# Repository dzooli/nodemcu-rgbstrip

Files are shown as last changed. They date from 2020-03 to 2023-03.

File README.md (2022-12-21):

# nodemcu-rgbstrip

FOSSA Status (https://app.fossa.io/projects/git%2Bgithub.com%2Fdzooli%2Fnodemcu-rgbstrip?ref=badge_shield)


This project is a quick study for home automation with Domoticz, NodeMCU WiFi and an RGB LED strip.

## Control an RGB Led strip with NodeMCU using Domoticz RGB Dimmer controller

### HW Components

- Raspberry Pi3
- NodeMCU
- Transistors
- Voltage regulators
- Resistances
- RGB LED strip

### SW Components

- IDE: PlatformIO
- ESP8266 Board family for Arduino
- WiFi AP (currently a Raspberry Pi3)
- WifiManager library for Arduino
- Domoticz on the RPi3

[Details here](https://github.com/dzooli/nodemcu-rgbstrip/blob/master/doc/devlog.md)

## License

FOSSA Status (https://app.fossa.io/projects/git%2Bgithub.com%2Fdzooli%2Fnodemcu-rgbstrip?ref=badge_large)

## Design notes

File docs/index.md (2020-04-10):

# Development of a Domoticz controlled ESP8266 RGB LED Strip Dimmer

## Introduction

Main purpose of this project is to create a WiFi controlled RGB lamp and integrate it into the Domoticz ecosystem. This is a learning oriented project for myself not a production-ready one.

Secondary goal is to use free and/or Open Source Software whenever is possible.

## System overview

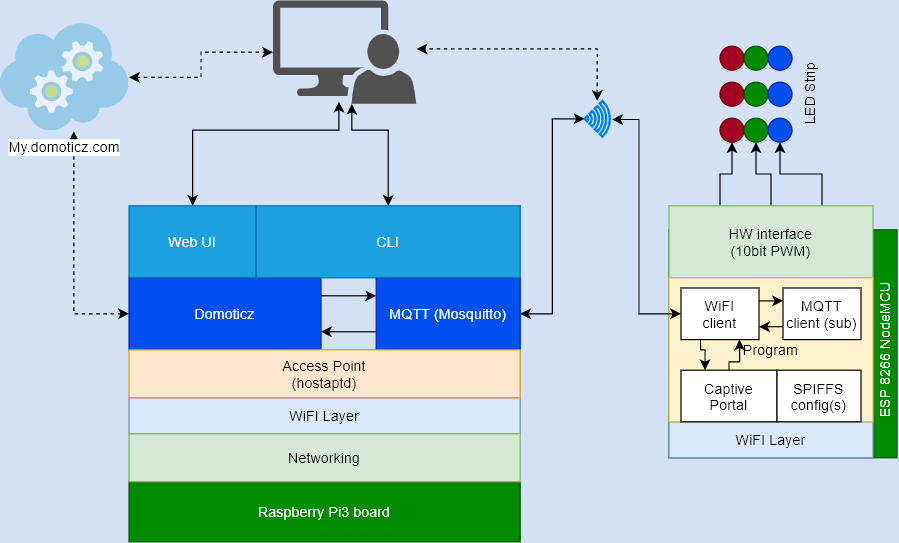
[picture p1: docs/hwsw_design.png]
Overall system design


## Client circuit

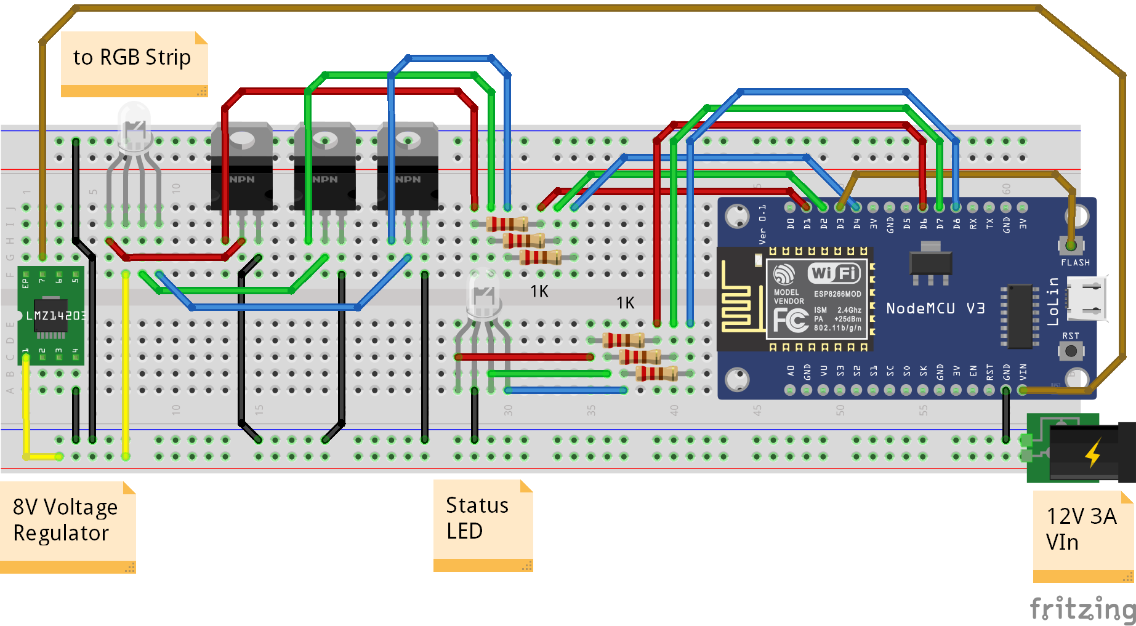
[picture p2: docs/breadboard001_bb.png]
Client schematic


## Captive portal
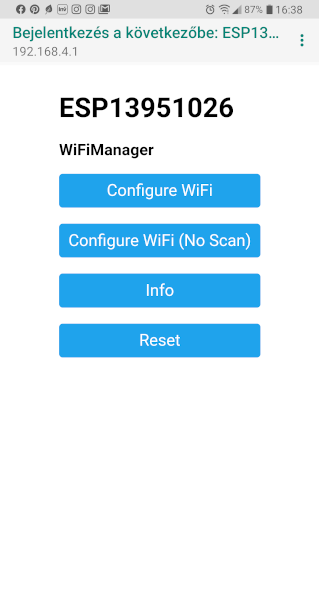
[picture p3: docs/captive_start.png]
Captive portal main

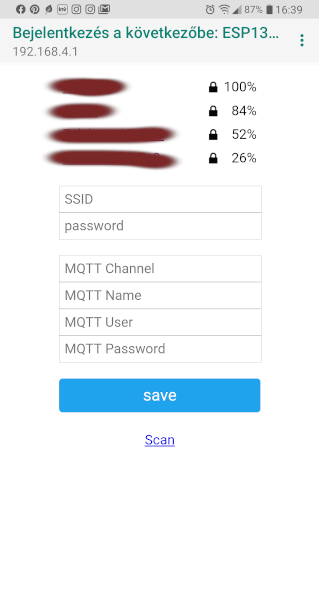
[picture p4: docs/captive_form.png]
Captive portal form


### Why Domoticz

- Good documentation with lot of examples
- Tons of ready-made sensors and actuators
- Active development (yearly stable major versions)
- Easy setup (unpack, setup and run as a service)
- **MQTT capable** => custom sensors with small effort (see the running External Pi Temperature script below)

#### Example custom script (cputemp2domoticz)

Send the DS3121's temparature sensor's value to Domoticz in every REFRESH=5 secs using basic Unix commands. The sensor index in Domoticz is _1_ in this example.

```bash
#!/bin/bash

export MQTTHOST=localhost; 
export TEMP_IDX=1; 
export REFRESH=5

while true; do
  echo '{"idx": '${TEMP_IDX}',"nvalue": 0.00, "svalue":"'$(sensors -u| grep temp1_input| \
  cut -d\  -f4)'"}' | mosquitto_pub -h $MQTTHOST -u xxxx -P yyyyy -t 'domoticz/in' -l  
  sleep ${REFRESH}
done
```

#### Run it as a "soft-daemon"

```bash
#!/bin/bash
export SCREENNAME="scriptedDomoticz"

for scriptname in *2domoticz; do 
    echo "Starting ${scriptname} in a detached screen..."
    screen -dmS ${SCREENNAME} ./${scriptname}
done    
```

## Used Tools and external libraries

- Json Assistant: https://arduinojson.org/v5/assistant
- Mosquitto MQTT server and CLI tools
- Flooplanner: https://floorplanner.com
- Arduino IDE v1.8.10 with 3rd-party ESP8266 devtools
- Marp - Markdown based presentation generator with built-in server and file watcher
- Drawing.io for diagram creation
- [Fritzing](https://fritzing.org) for BreadBoard sketching
- Eagle for schematic and PCB design (_coming soon_)

## Problems and solutions

- Chrome has JS cache -> IP has been changed but there was no HTTP error message just a Domoticz-like page with "Offline" message comes from the cache -> solution: check the IP address after a router reboot :)
- FPSTR is not working properly with ESP8266 2.4.1-> use F("") (inline PROGMEM strings ) instead
- Domoticz's Dimmer MQTT packet is bigger than 400 bytes, PubSubClient has a 128 bytes buffer -> Increase buffer size to 512 bytes in PubSubClient.h
- PWM resolution is too small. Only 10 level per color component is possible which means 10x10x10=1000 different colors. -> Possible solution: usage of ESP8266 SDK without Arduino. Not tested, needs complete rewrite and a different toolchain usage.

## Improvement ideas

- Use MQTT-SN instead of TCP based MQTT
  - smaller energy footprint,
  - longer battery operation time for future projects,
  - exmaple usages with pros: ToF sensors, environmental sensors, PIR motion detectors
- Add a backup AP possibility
- Add MQTT bridging possibility (for larger environments and distant sensors)
- GeoFencing with [OwnTracks](https://owntracks.org/) and [OwnTracks recorder](https://github.com/owntracks/recorder) and a VPS

## Future improvement ideas

- Integrate more sensors (light levels, door contacts, external temperature sensors)
- Simulate the dawn in my room :)
- Custom dashboard with Node-Red
- Try [MyDomoticz.com](https://my.domoticz.com) the publicly available Domoticz Hub for integrate private Domoticz instances into a publicly available Cloud based solution

## Security related ideas

- Use certificate based MQTT connection
- MAC address filtering for the RPi AP
- HTTPS connection for the Domoticz instance (Let's encrypt or self-signed)
- Use Realtek's PADI DevKit instead of ESP8266 due to not fully open source of ESP8266

## Mixed info

### Domoticz HTTP GET format examples

- Domoticz format for a Temperature+Humidity+HumidityStatus sensor (SparkFun_Si7021_Breakout): **/json.htm?type=command&param=udevice&idx=IDX&nvalue=0&svalue=TEMP;HUM;HUM_STAT**

### Other custom firmware and solutions

- Other implementation with OTA+MQTT: [https://git.jeckyll.net/published/personal/esp8266/esp-mqtt-ota-rgb-led-light-new-pwm/tree/master](https://git.jeckyll.net/published/personal/esp8266/esp-mqtt-ota-rgb-led-light-new-pwm/tree/master)
- Other implementation with Basic code: [http://lucstechblog.blogspot.com/2018/04/rgb-strip-control-over-wifi-part-2.html](http://lucstechblog.blogspot.com/2018/04/rgb-strip-control-over-wifi-part-2.html)
- [Same setup with MQTT and ESP8266](https://xubecblog.wordpress.com/2019/01/14/esp8266-controlled-rgb-led-strip/)
- [With alternative driver parts](https://tigoe.github.io/LightProjects/led-strips.html)
- ESPEasy
- Tasmota with [Tasmotizer](https://github.com/tasmota/tasmotizer): Easily customisable firmware with a lot of possibilities and modified commercial client tutorials (for example: it is usable with a common OBI's WiFi wall plug adapter)
- [https://www.mysensors.org/](https://www.mysensors.org/)

## Links and Tutorials

### Project related

- __Github__ repository: [https://github.com/dzooli/nodemcu-rgbstrip/](https://github.com/dzooli/nodemcu-rgbstrip/)
- Fritzing project: [https://fritzing.org/projects/nodemcu-rgb-strip](https://fritzing.org/projects/nodemcu-rgb-strip)  

### Domoticz related

- [https://www.domoticz.com/forum/viewforum.php?f=51](https://www.domoticz.com/forum/viewforum.php?f=51)
- [https://www.domoticz.com/wiki/ESP8266_WiFi_module](https://www.domoticz.com/wiki/ESP8266_WiFi_module)
- [https://blog.quindorian.org/2014/12/esp8266-wifi-led-dimmer-part-1-of-x.html/](https://blog.quindorian.org/2014/12/esp8266-wifi-led-dimmer-part-1-of-x.html/)
- [http://blog.quindorian.org/wp-content/uploads/2016/07/ESPworkshop2016.7z](http://blog.quindorian.org/wp-content/uploads/2016/07/ESPworkshop2016.7z)
- [https://www.domoticz.com/forum/viewtopic.php?t=12934](https://www.domoticz.com/forum/viewtopic.php?t=12934)

### MQTT related

- [http://www.steves-internet-guide.com/mosquitto-tls/](http://www.steves-internet-guide.com/mosquitto-tls/)
- [https://mcuoneclipse.com/2017/04/14/enable-secure-communication-with-tls-and-the-mosquitto-broker/](https://mcuoneclipse.com/2017/04/14/enable-secure-communication-with-tls-and-the-mosquitto-broker/)
- [https://www.digitalocean.com/community/tutorials/how-to-install-and-secure-the-mosquitto-mqtt-messaging-broker-on-ubuntu-16-04](https://www.digitalocean.com/community/tutorials/how-to-install-and-secure-the-mosquitto-mqtt-messaging-broker-on-ubuntu-16-04)

### Interesting projects

- [Self-driving car project](https://github.com/hunter0713/EECS388_Final_Project)

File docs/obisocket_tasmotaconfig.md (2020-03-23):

## Generic 18

```c
D2 GPIO4 - Relay1 (21)
D1 GPIO5 - Button1 (17)
D6 GPIO12 Relay1 Led1i (56)
D7 GPIO13 Led1i Led2 (53)
```

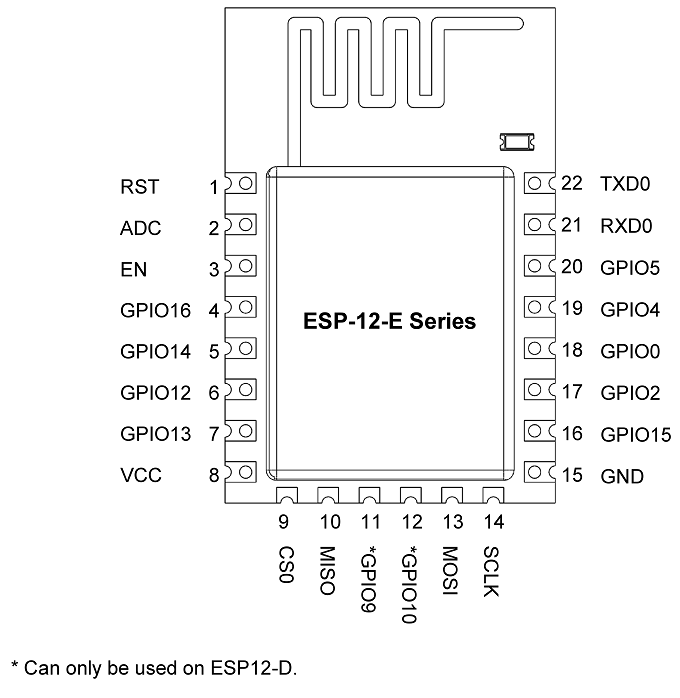
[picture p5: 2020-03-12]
docs/esp8266_pinout.png

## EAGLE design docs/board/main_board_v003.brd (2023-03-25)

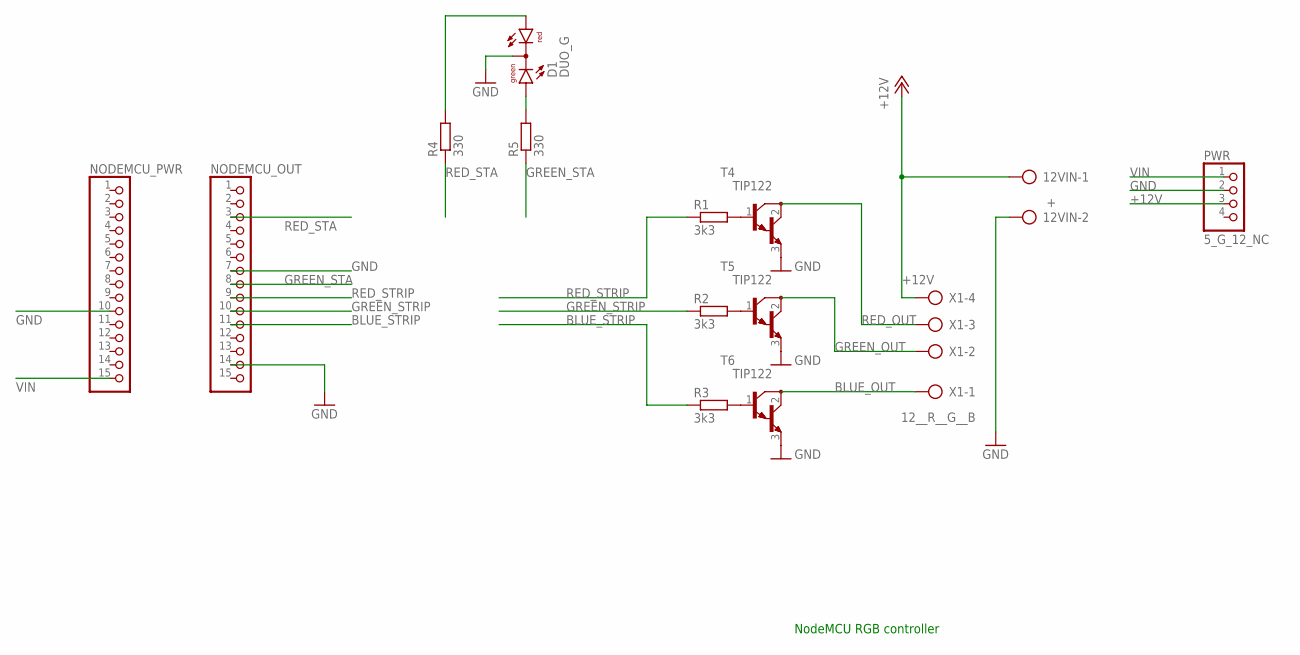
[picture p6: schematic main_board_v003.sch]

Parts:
12VIN: +; AK500/2-H
D1: DUO_G; DUOLED2X5
NODEMCU_OUT: PINHD-1X15; 1X15
NODEMCU_PWR: PINHD-1X15; 1X15
PWR: 5_G_12_NC; 1X04
R1, R2, R3: 3k3; 0207/10
R4, R5: 330; 0207/10
T4, T5, T6: TIP122; TO220
X1: 12__R__G__B; AK500/4-H

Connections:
+12V: 12VIN.1, PWR.3, X1.4
BLUE_OUT: T6.2 (C), X1.1
BLUE_STRIP: NODEMCU_OUT.11, R3.1
GND: 12VIN.2, D1.K (C), NODEMCU_OUT.7, NODEMCU_OUT.14, NODEMCU_PWR.10, PWR.2, T4.3 (E), T5.3 (E), T6.3 (E)
GREEN_OUT: T5.2 (C), X1.2
GREEN_STA: NODEMCU_OUT.8, R5.1
GREEN_STRIP: NODEMCU_OUT.10, R2.1
unnamed: R1.2, T4.1 (B)
unnamed: R2.2, T5.1 (B)
unnamed: R3.2, T6.1 (B)
unnamed: D1.AR, R4.2
unnamed: D1.AG, R5.2
RED_OUT: T4.2 (C), X1.3
RED_STA: NODEMCU_OUT.3, R4.1
RED_STRIP: NODEMCU_OUT.9, R1.1
VIN: NODEMCU_PWR.15, PWR.1

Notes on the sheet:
NodeMCU RGB controller

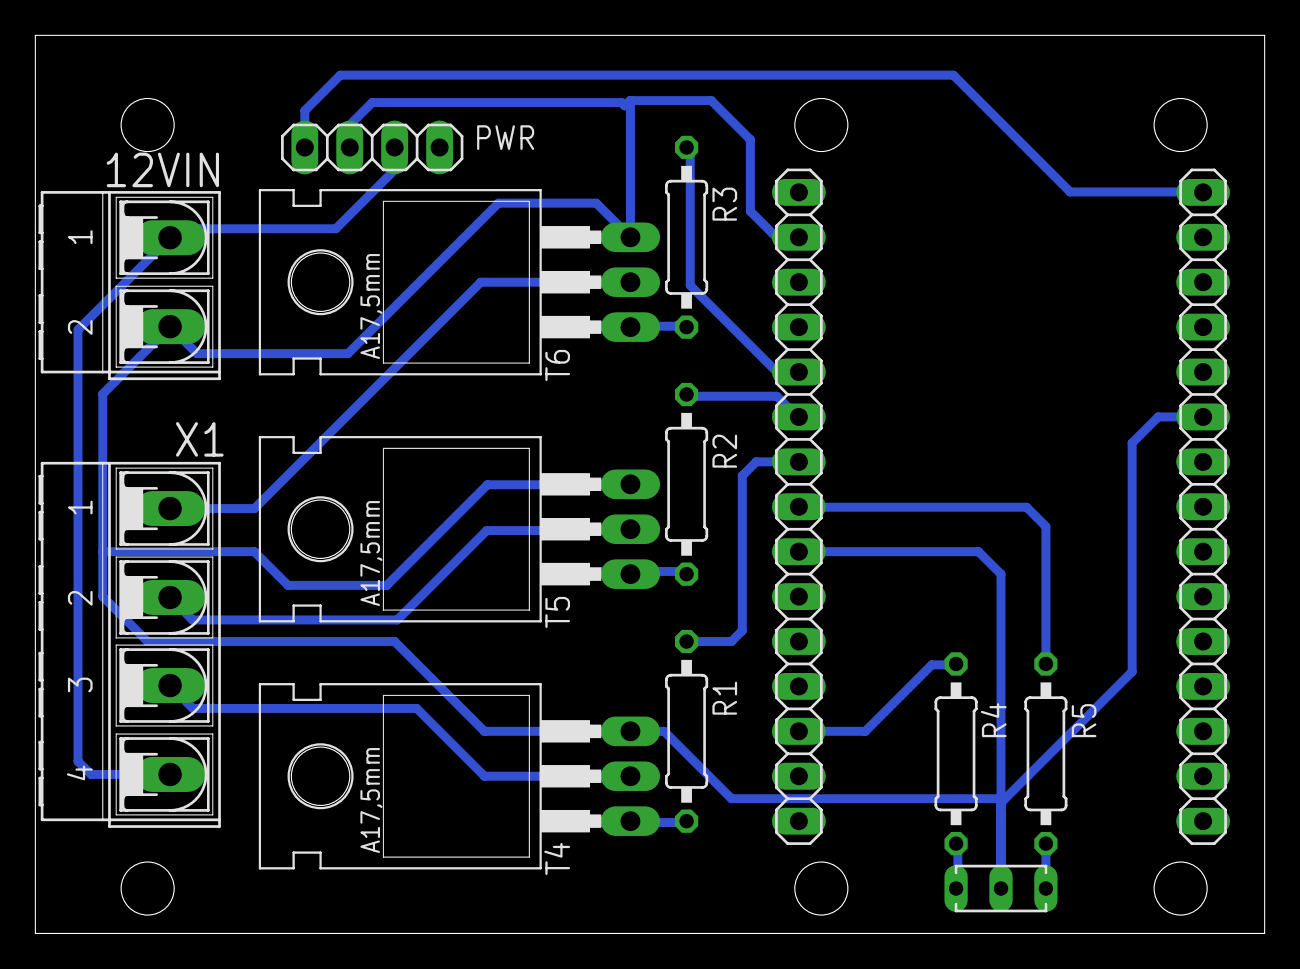
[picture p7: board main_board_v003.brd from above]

Board: 2 copper layers, 69.5 x 50.8 mm, 14 parts (0 on the bottom side), 16 nets.

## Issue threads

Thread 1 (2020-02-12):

Process the MQTT payload

dzooli, 2020-02-12:
This is the next main improvement of the project. The program is able to filter the payload if it is targeted to the current device based on the MQTT Friendly Name parameter.
The program has to be reactive to the targeted payload.

https://app.leanboard.io/board/2b5bddad-8570-4da9-9b39-e13ee751a42b

dzooli, 2020-03-24:
Processing of the payload is done and output level setting is works as expected.

Closed 2020-03-24.

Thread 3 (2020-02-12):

Reload the RGB LED state

dzooli, 2020-02-12:
If an MQTT message contains (n|s)value other than 0 and the current state is OFF the program has to reload the saved state from an SPIFFS file.

dzooli, 2020-04-11:
Closed as a duplicate

Closed 2020-04-11.

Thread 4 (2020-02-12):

Check the memory fragmentation

dzooli, 2020-02-12:
Reboot the NodeMCU if the memory fragmentation is above 80%. Save the state before.

dzooli, 2020-03-23:
Get memory fragmentation is done and printed to the serial port.
TODO:
 - reset the MCU when the fragmentation is bigger than 80%

dzooli, 2020-03-24:
MCU is resetting upon more than 80% memory fragmentation.

Closed 2020-03-24.

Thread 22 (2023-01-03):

PWM range fix

dzooli, 2023-01-03:
On ESP8266 the PWM is 10bit wide, so we need to extend the range from 0-255 to 0-1023 to use the full output of the LED strip.

Closed 2023-03-21.

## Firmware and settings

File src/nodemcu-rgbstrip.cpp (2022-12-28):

#include <Arduino.h>
#include <Esp.h>
#include <FS.h>
#include <LittleFS.h>
#include <ESP8266WiFi.h> //https://github.com/esp8266/Arduino
#include <WiFiManager.h> //https://github.com/tzapu/WiFiManager
#include <ArduinoJson.h> //https://github.com/bblanchon/ArduinoJson
#include <PubSubClient.h>
#include <strings.h>
#include <memory>

#include "DomoticzRGBDimmer.h"
#include "rgbstrip_types.h"
#include "rgbstrip_macros.h"
#include "rgbstrip_constants.h"
#include <MQTTRGB.h>
#include <RGBStripWifi.h>

#define DEBUG 1
#include "debugprint.h"

/* Function declarations for C++ compatibility */
void setOutput(int r, int g, int b, int level);
bool subscribeMQTT(const char *user, const char *pass, const char *topic, const char *clientid);
void mqttCallback(char *topic, uint8_t *payload, unsigned int len);

/* Global variables */
String stassid = "";
String stapass = "";
String mqtt_channel = "";
String mqtt_fname = "";
String mqtt_user = "";
String mqtt_pass = "";

WiFiClient wfClient;
PubSubClient mqttC(wfClient); // The MQTT client
WiFiManager wfMan;

WiFiManagerParameter mqttchannel("mqttchannel", "MQTT Channel", mqtt_channel.c_str(), MQTT_CLEN);
WiFiManagerParameter mqttfname("mqttfname", "MQTT Name", mqtt_fname.c_str(), MQTT_FLEN);
WiFiManagerParameter mqttuser("mqttuser", "MQTT User", mqtt_user.c_str(), MQTT_ULEN);
WiFiManagerParameter mqttpass("mqttpass", "MQTT Password", mqtt_pass.c_str(), MQTT_PLEN);

void saveWifiConfigCallback()
{
    DEBUGPRINT("Saving configuration to the filesystem...");
    // Store the credentials for using it in the program
    stassid = WiFi.SSID();
    stapass = WiFi.psk();
    File configFile = LittleFS.open(CONFNAME, "w");
    if (!configFile)
    {
        DEBUGPRINT("ERROR: Cannot open config file for write!");
        return;
    }
    StaticJsonBuffer<400> jsonBuffer;
    JsonObject &json = jsonBuffer.createObject();
    json["sta_ssid"] = stassid;
    json["sta_pass"] = stapass;
    json["mqtt_channel"] = mqttchannel.getValue();
    json["mqtt_fname"] = mqttfname.getValue();
    json["mqtt_user"] = mqttuser.getValue();
    json["mqtt_pass"] = mqttpass.getValue();
    json.printTo(configFile);
    configFile.flush();
    configFile.close();
    delay(200);
}

void configModeCallback(WiFiManager *myWfMan)
{
    Serial.println(F("Captive portal parameters:"));
    Serial.println(WiFi.softAPIP());
    Serial.println(WiFi.softAPmacAddress());
    Serial.println(myWfMan->getConfigPortalSSID());
}

std::unique_ptr<rgbstatus> loadStripStatus()
{
    File statfile = LittleFS.open(STATFILE, "r");
    if (!statfile)
    {
        DEBUGPRINT("Cannot open strip status file");
        return nullptr;
    }
    // Start processing
    size_t size = statfile.size();
    std::unique_ptr<char[]> buf(new char[size]);
    statfile.readBytes(buf.get(), size);
    DynamicJsonBuffer jsonBuffer;
    JsonObject &json = jsonBuffer.parseObject(buf.get());
    if (!json.success())
    {
        DEBUGPRINT("Cannot parse status file!");
        return nullptr;
    }
    auto res = std::make_unique<rgbstatus>();
    res->r = (unsigned char)json.get<char>("red");
    res->g = (unsigned char)json.get<char>("green");
    res->b = (unsigned char)json.get<char>("blue");
    res->l = (unsigned char)json.get<char>("level");
    return res;
}

bool saveStripStatus(int r, int g, int b, int l)
{
    File statfile = LittleFS.open(STATFILE, "w");
    if (!statfile)
    {
        DEBUGPRINT("ERROR: Cannot open status file for write!");
        return false;
    }
    StaticJsonBuffer<400> jsonBuffer;
    JsonObject &json = jsonBuffer.createObject();
    json["red"] = r;
    json["green"] = g;
    json["blue"] = b;
    json["level"] = l;
    json.printTo(statfile);
    statfile.flush();
    statfile.close();
    DEBUGPRINT("Status file saved successfully.");
    return true;
}

void pinSetup()
{
    // PWM outputs
    pinMode(D6, OUTPUT); /* RED */
    pinMode(D8, OUTPUT); /* GREEN */
    pinMode(D7, OUTPUT); /* BLUE */
    // STATUS LEDS
    pinMode(D2, OUTPUT); // RED status LED
    pinMode(D5, OUTPUT); // GREEN status LED
    pinMode(D4, OUTPUT); // BLUE status LED

    pinMode(D3, INPUT_PULLUP); /* for the FLASH => reset config button */
}

void setup()
{
    boolean hasSavedConfig = false;

    Serial.begin(115200);

    pinSetup();

    /* remove saved config and restart if the flash button is pushed */
    attachInterrupt(digitalPinToInterrupt(D3), deleteWifiConfig, CHANGE);

    selfTest();

    if (!LittleFS.begin())
    {
        DEBUGPRINT("Failed to mount LittleFS");
        ESP.reset();
    }

    // Last RGB status reload
    if (std::unique_ptr<rgbstatus> restoredValues = loadStripStatus())
    {
        setOutput(restoredValues->r, restoredValues->g, restoredValues->b, restoredValues->l);
    }

    // Wifi config file exists, reading and loading
    File configFile = LittleFS.open(CONFNAME, "r");
    if (configFile)
    {
        size_t size = configFile.size();
        // Allocate a buffer to store contents of the file.
        std::unique_ptr<char[]> buf(new char[size]);

        configFile.readBytes(buf.get(), size);
        DynamicJsonBuffer jsonBuffer;
        JsonObject &json = jsonBuffer.parseObject(buf.get());
        if (json.success())
        {
            stassid = String((const char *)json["sta_ssid"]);
            stapass = String((const char *)json["sta_pass"]);
            mqtt_channel = String((const char *)json["mqtt_channel"]);
            mqtt_fname = String((const char *)json["mqtt_fname"]);
            mqtt_user = String((const char *)json["mqtt_user"]);
            mqtt_pass = String((const char *)json["mqtt_pass"]);

            hasSavedConfig = true;
        }
        else
        {
            DEBUGPRINT("Configuration parse failed!");
        }
    }
    else
    {
        DEBUGPRINT("Configuration file cannot be opened!");
    }

    /* No saved config file => start in AP mode with the config portal */
    if (!hasSavedConfig)
    {
        SLEDS_OFF
        delay(50);
        CAPTIVE_ON
        // Setup WiFiManager and start the config portal
        String ssid = "ESP" + String(ESP.getChipId());
        wfMan.setConfigPortalTimeout(180);
        wfMan.setAPCallback(configModeCallback);
        wfMan.setSaveConfigCallback(saveWifiConfigCallback);
        wfMan.setMinimumSignalQuality(10);
        wfMan.setBreakAfterConfig(true);
        wfMan.setDebugOutput(false);

        // Custom parameters
        wfMan.addParameter(&mqttchannel);
        wfMan.addParameter(&mqttfname);
        wfMan.addParameter(&mqttuser);
        wfMan.addParameter(&mqttpass);

        WiFi.disconnect(true);
        wfMan.startConfigPortal(ssid.c_str());
    }

    /* Connect to the AP if not connected by the WiFiManager */
    delay(500);
    DEBUGPRINT("Connecting to the AP...");
    SLEDS_OFF
    bool wfConnected = initWiFiStation(stassid, stapass);
    if (!wfConnected)
    {
        WiFi.printDiag(Serial);
        ERROR_ON
        delay(1000);
        DEBUGPRINT("Cannot connect to the AP. Resetting...");
        ESP.reset();
    }
    OK_ON

    /* Initializing the connection with the MQTT broker */
    SLEDS_OFF
    mqttC.setServer(WiFi.gatewayIP(), MQTT_SERVER_PORT);
    mqttC.setBufferSize(512);
    mqttC.setCallback(mqttCallback);
    if (!hasSavedConfig)
    {
        mqtt_user = mqttuser.getValue();
        mqtt_pass = mqttpass.getValue();
        mqtt_fname = mqttfname.getValue();
        mqtt_channel = mqttchannel.getValue();
    }
    subscribeMQTT(mqtt_user.c_str(), mqtt_pass.c_str(), mqtt_channel.c_str(), mqtt_fname.c_str());
    if (!mqttC.connected())
    {
        DEBUGPRINT("Initial connection to the MQTT broker has been failed!");
        ERROR_ON
    } else {
        DEBUGPRINT("WiFi and MQTT has been connected successfully. Processing...");
        OK_ON
    }
}

bool subscribeMQTT(const char *user, const char *pass, const char *topic, const char *clientid)
{
    bool res = false;
    int connTry = MAX_CONNTRY;
    while (connTry--)
    {
        mqttC.connect(clientid, user, pass);
        delay(50);
        if (mqttC.connected())
        {
            mqttC.subscribe(topic);
            DEBUGPRINT("Connected to the MQTT broker.");
            res = true;
            break;
        }
    }
    return res;
}

void mqttCallback([[maybe_unused]] char *topic, uint8_t *payload, unsigned int len)
{
    payload[len] = 0;

    if (strstr((const char *)payload, mqtt_fname.c_str()))
    {

        int fragPercent = 0;

        DomoticzRGBDimmer dimmerParams = parseDomoticzRGBDimmer((const char *)payload);
#ifdef DEBUG
        Serial.println(F("Payload target is this device. Processing payload..."));
        Serial.println(F("Setting PWM levels to: "));
        Serial.print(F("  R:     "));
        Serial.println(dimmerParams.Color_r);
        Serial.print(F("  G:     "));
        Serial.println(dimmerParams.Color_g);
        Serial.print(F("  B:     "));
        Serial.println(dimmerParams.Color_b);
        Serial.print(F("  Level: "));
        Serial.println(dimmerParams.Level);
        Serial.print(F("  Value: "));
        Serial.println(dimmerParams.nvalue);
#endif

        setOutput(dimmerParams.Color_r, dimmerParams.Color_g, dimmerParams.Color_b, (!dimmerParams.nvalue) ? 0 : dimmerParams.Level);
        saveStripStatus(dimmerParams.Color_r, dimmerParams.Color_g, dimmerParams.Color_b, (!dimmerParams.nvalue) ? 0 : dimmerParams.Level);

        DEBUGPRINT("Releasing resources...");
        freeDomoticzRGBDimmer(&dimmerParams);

        fragPercent = ESP.getHeapFragmentation();
        if (fragPercent > 80)
        {
            DEBUGPRINT("Fragmentation is too high! Rebooting...");
            ESP.reset();
        }
    }
}

void setOutput(int r, int g, int b, int level)
{
    if (level == 0)
    {
        analogWrite(D6, 0);
        analogWrite(D8, 0);
        analogWrite(D7, 0);
        return;
    }
    analogWrite(D6, map((r * level), 0, 25500, 0, 1023));
    analogWrite(D8, map((g * level), 0, 25500, 0, 1023));
    analogWrite(D7, map((b * level), 0, 25500, 0, 1023));
}

void loop()
{
    SLEDS_OFF
    if (WiFi.isConnected())
    {
        if (mqttC.connected())
        {
            mqttC.loop();
            BOOT_ON
        }
        else
        {
            Serial.println(F("Reconnecting to the MQTT broker..."));
            subscribeMQTT(mqtt_user.c_str(), mqtt_pass.c_str(), mqtt_channel.c_str(), mqtt_fname.c_str());
        }
    }
    else
    {
        ERROR_ON
        Serial.println(F("Reconnecting WiFi AP..."));
        mqttC.disconnect();
        WiFi.disconnect();
        initWiFiStation(stassid, stapass);
    }
    delay(100);
}

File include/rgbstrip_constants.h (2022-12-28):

#ifndef __RGBSTRIP_CONST_H__

#define __RGBSTRIP_CONST_H__

/* Global constants */
#define MQTT_SERVER_PORT 1883
#define MAX_CONNTRY 5
#define PWM_FREQ 100
#define CONFNAME "/wificreds.conf"
#define STATFILE "/status.conf"

/*
   Definitions for the MQTT parameters
*/
#define MQTT_CLEN 80 // channel string length
#define MQTT_ULEN 20 // username length
#define MQTT_PLEN 20 // password length
#define MQTT_FLEN 20 // friendly name length

#endif

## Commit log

2017-07-31 Initial arduino script
2017-08-21 output pin changed d1=red, d2=green, d3=(input on NodeMCU1 | flash button, d4=blue) and comments added
2018-08-31 Automatic connection to a preconfigured AP is ok. Status LED handling macros. Status feedback with LEDs. MQTT parameter enrty on the captive portal.
2019-12-02 MQTT parameter length to constants, status led update on successful WiFI connection
2020-01-29 MQTT payload parser implementation started. Added high resolution PWM routines
2020-02-09 MQTT payload is filtered by the device's friendly name. Hi-res PWM has been removed.
2020-03-23 Added Fritzing breadboard and Drawing.io HWSW design images and sources
    [breadboard001.fzz]
2020-03-24 Added PWM output setup and switching OFF functionality. Just works.
2020-03-24 Pin layout changed to be more NodeMCU compatible
    [breadboard001.fzz]
2020-04-07 breadboard update
    [breadboard002.fzz]
2022-12-20 moved to platformIO
    [breadboard001.fzz, breadboard002.fzz]
2022-12-20 separated doc directory
    [breadboard001.fzz, breadboard002.fzz]
2022-12-20 moved to LittleFS and minor fixes
    [nodemcu-rgbstrip.cpp]
2022-12-21 Added SonarCloud badge
2022-12-21 GitHub Pages try
    [breadboard001.fzz, breadboard002.fzz]
2022-12-26 sample status file
2022-12-27 cleanup and pin layout changes
2023-03-25 added board plans
    [main_board_v003.brd, main_board_v003.sch]
